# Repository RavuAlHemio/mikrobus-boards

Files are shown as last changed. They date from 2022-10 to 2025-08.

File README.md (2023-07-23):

# mikroBUS Boards

An assortment of boards that should be compatible with [MikroElektronika](https://www.mikroe.com/)'s [mikroBUS standard](https://download.mikroe.com/documents/standards/mikrobus/mikrobus-standard-specification-v200.pdf).

The designs are experimental. They are provided without warranty that the resulting boards will be fit for purpose and without warranty that they will not damage the connected devices.

## Boards

* `i2c-spi-jumper-mikrobus-board`: an I²C-to-SPI interface similar to the [_I2C to SPI Click_](https://www.mikroe.com/i2c-to-spi-click) (MIKROE-3743) and using the same chip ([NXP SC18IS602BIPW/S8HP](https://www.nxp.com/part/SC18IS602BIPW)), but with pin header jumpers instead of re-soldering 0Ω SMD "resistors" to set the I²C address. Perfect for people with no fine motor skills, like myself.

* `i2c-spi-jumper-mikrobus-board-var2`: another I²C-to-SPI interface with jumpers, but using the [NXP SC18IS606PW](https://www.nxp.com/part/SC18IS606PW), since the SC18IS602BIPW/S8HP is end-of-life. A different board is needed because the new chip has a different pinout.

* `i2c-spi-oled-mikrobus-board`: an I²C-to-SPI interface with a pinout that helps interoperability with the [_OLED C Click_] (https://www.mikroe.com/oled-c-click) (MIKROE-1585) by making some of its additional non-SPI pins accessible via I²C while isolating them from the microcontroller. To simplify the traces and keep the board a reasonable size, instead of providing a second pair of mikroBUS sockets to connect the SPI-enabled device, the design provides a [mikroBUS Shuttle](https://www.mikroe.com/mikrobus-shuttle) pin header.

* `i2c-uart-mikrobus-board`: just as the I²C-to-SPI boards allow SPI devices to be controlled via I²C, this board allows UART devices to be contacted via I²C. Based around the [NXP SC16IS740IPW](https://www.nxp.com/part/SC16IS740IPW). This board also provides a [mikroBUS Shuttle](https://www.mikroe.com/mikrobus-shuttle) pin header to connect the UART board. The I²C address is set using rotary switches.

* `knx-mikrobus-board`: a KNX bus coupling unit (BCU) that translates between KNX and UART. Based around the [onsemi NCN5130](https://www.onsemi.com/products/interfaces/wired-transceivers-modems/ncn5130) but should also work with the pin-compatible [onsemi NCN5121](https://www.onsemi.com/products/interfaces/wired-transceivers-modems/ncn5121).

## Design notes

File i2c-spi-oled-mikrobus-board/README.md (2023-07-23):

# `i2c-spi-oled-mikrobus-board`

I²C-to-SPI interface board with most mikroBUS pins controllable via I²C.

Combines two chips: SC18IS606PW (I²C-to-SPI) and PCA9557PW (I²C-to-GPIO).

## Addressing

Three bits of the address are chosen through the three jumpers on JP1. The bits are numbered, from
top to bottom, A0, A1, and A2. Bridging the left and middle pins with the jumper sets that bit to 0;
bridging the middle and right pins sets the bit to 1.

Once the jumpers are set, the following addresses are assigned to the chips:

| chip | MSB | b5 | b4 | b3 | b2 | b1 | LSB | (R/W) |
| --- | --- | -- | -- | -- | -- | -- | --- | ----- |
| SC18IS606PW | 0 | 1  | 0  | 1  | A2 | A1 | A0  | |
| PCA9557PW | 0 | 0  | 1  | 1  | A2 | A1 | A0  | |

### Communication

The shuttle board's peripheral select pin is connected to the SC18IS606PW's ¬SS0 pin. Therefore, to
send data via SPI, use function 0x01.

The non-SPI pins are connected to the PCA9557PW as follows:

| PCA9557PW | shuttle board |
| --- | --- |
| P0 | ¬INT |
| P1 | D/¬C |
| P2 | EN |
| P3 | R/¬W |
| P4 | ¬RST |

Pins P5 through P7 are unconnected.

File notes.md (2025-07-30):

## mikroBUS Shuttle

The pin header used by MikroElektronika for the mikroBUS Shuttle is a CNC 3221-16-0300-00, available from DigiKey (not Mouser). Most other shrouded pin headers do not have the "open sides" (or only have them at the bottom of the pin header but not near the top).

The canonical pin numbering for IDC connectors is:

1. The key is a protrusion on the connector with sockets (generally on a cable) and a hole on the connector with pins (generally on a device).

2. The row with the key or key-hole is the top row.

3. In the top row, position 1 is the leftmost socket (and, correspondingly, the rightmost pin) when staring at the mating surface of the connector.

4. Position 2 is in the next row right below position 1.

5. Once all rows are exhausted, counting continues at the next position in the top row.

Oddly enough, the Shuttle's ribbon cables are terminated in such a way that pin 1 is top-left on one end of the cable and top-right on the other. This means that the pinout of the Shuttle board (the remote base for a mikroBUS board) is different than that of the Shuttle Click board (the module that plugs into a host board).

Taking all of this into account, the socket pinouts on the boards are as follows, key-hole above the top row.

mikroBUS Shuttle (remote):

| | | | | | | | |
| ---:| -----:| ----:| ----:| ----:| ----:| ---:| ---:|
| GND | +3.3V | COPI | CIPO |  SCK | CS | RST |  AN |
|  15 | 13 | 11 | 9 | 7 | 5 | 3 | 1 |
|  16 | 14 | 12 | 10 | 8 | 6 | 4 | 2 |
| GND | +5V |  SDA |  SCL | CRPT | CTPR | INT | PWM |

(CRPT and CPTR are the UART pins: Controller Rx/Peripheral Tx and vice versa. The two GND pins are connected together on the Shuttle. The connector is mounted "key-up".)

Shuttle click (base):

| | | | | | | | |
| ---:| ---:| ----:| ----:| ----:| ----:| -----:| ---:|
| PWM | INT | CTPR | CRPT |  SCL |  SDA | +5V | GND |
|  15 |  13 | 11 | 9 | 7 | 5 | 3 | 1 |
|  16 |  14 | 12 | 10 | 8 | 6 | 4 | 2 |
|  AN | RST | CS |  SCK | CIPO | COPI | +3.3V | GND |

(Here, too, the ground pins are connected internally. The connector is mounted "key-down", but the above table is oriented "key-up".)

## ARM SWD debug port

The partially-shrouded 1.27mm pin header used for the ARM SWD debug port is a Samtec FTSH-105-01-F-DV-K-P. The -K specifies the keyed partial shroud and -P specifies a pick & place pad for simplified machine assembly.

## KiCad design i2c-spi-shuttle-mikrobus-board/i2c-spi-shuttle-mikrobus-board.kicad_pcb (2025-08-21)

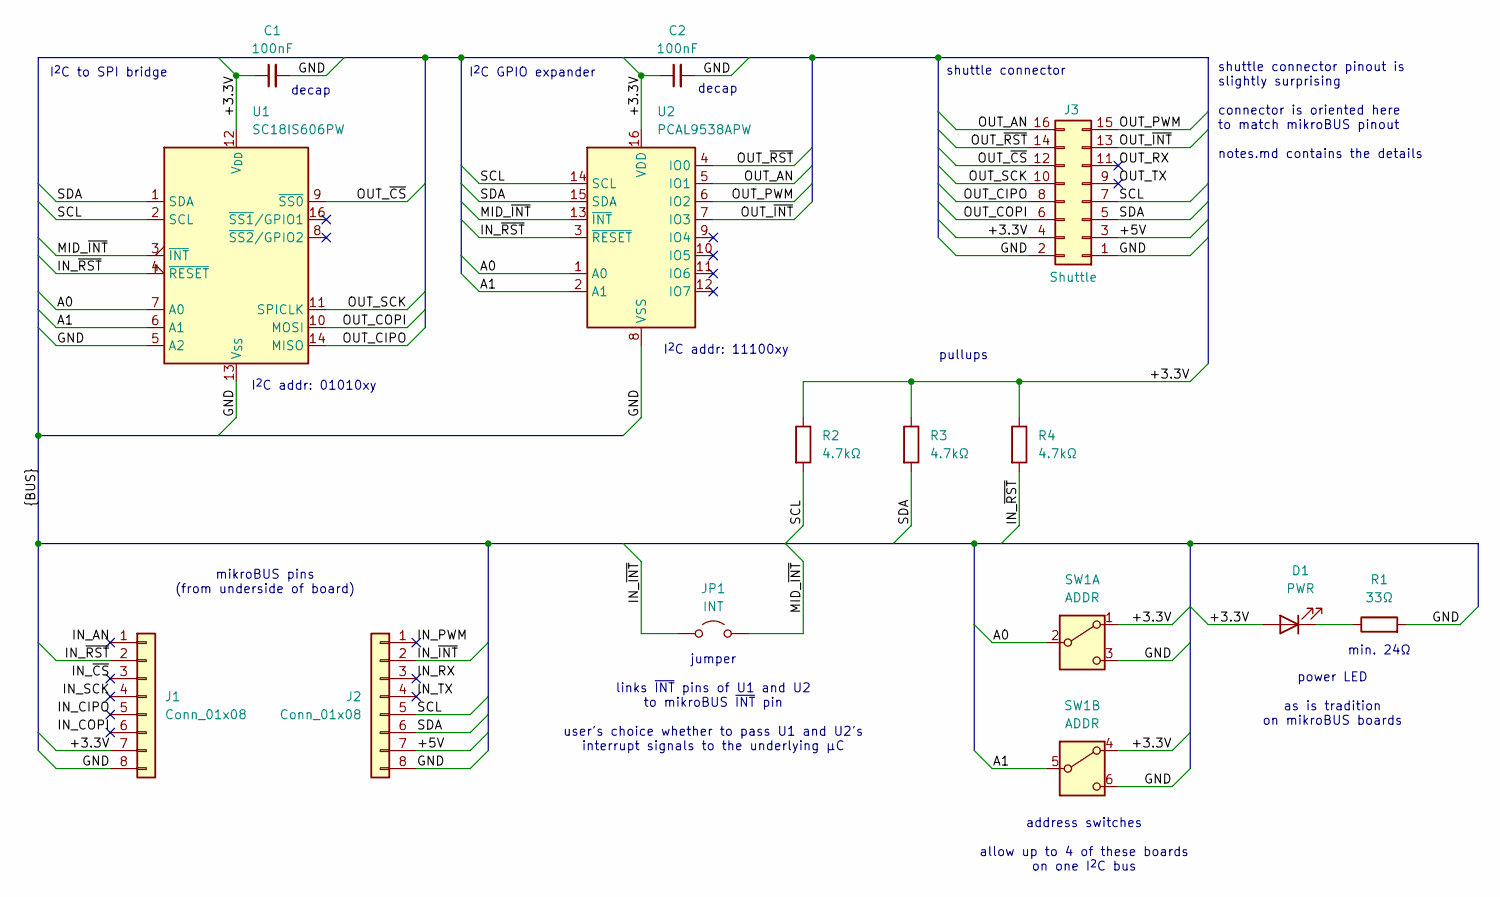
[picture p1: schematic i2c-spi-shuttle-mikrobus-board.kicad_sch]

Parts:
C1, C2: 100nF; C_0402_1005Metric; LCSC C307331
D1: PWR; LED_0805_2012Metric; LCSC C2297
J1, J2: Conn_01x08; PinHeader_1x08_P2.54mm_Vertical
J3: Shuttle; CNC_3221-16-0300-00; LCSC C5338669
JP1: INT; PinHeader_1x02_P2.54mm_Vertical
R1: 33Ω; R_0603_1608Metric; LCSC C23140
R2, R3, R4: 4.7kΩ; R_0402_1005Metric; LCSC C25900
SW1: ADDR; Nidec_Copal_CAS-D20A; LCSC C3664582
U1: SC18IS606PW; TSSOP-16_4.4x5mm_P0.65mm; LCSC C5190384
U2: PCAL9538APW; TSSOP-16_4.4x5mm_P0.65mm; LCSC C2652336

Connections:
/+3.3V: C1.1, C2.1, D1.2 (A), J1.7, J3.4, R2.1, R3.1, R4.1, SW1.1 (A), SW1.4 (A), U1.12 (V_{DD}), U1.15 (V_{DD}), U2.16 (VDD)
/+5V: J2.7, J3.3
/A0: SW1.2 (B), U1.7 (A0), U2.1 (A0)
/A1: SW1.5 (B), U1.6 (A1), U2.2 (A1)
/GND: C1.2, C2.2, J1.8, J2.8, J3.1, J3.2, R1.2, SW1.3 (C), SW1.6 (C), U1.5 (A2), U1.13 (V_{SS}), U2.8 (VSS)
/IN_AN: J1.1
/IN_CIPO: J1.5
/IN_COPI: J1.6
/IN_PWM: J2.1
/IN_RX: J2.3
/IN_SCK: J1.4
/IN_TX: J2.4
/IN_~CS: J1.3
/IN_~INT: J2.2, JP1.1 (A)
/IN_~RST: J1.2, R4.2, U1.4 (~RESET), U2.3 (~RESET)
/MID_~INT: JP1.2 (B), U1.3 (~INT), U2.13 (~INT)
/OUT_AN: J3.16, U2.5 (IO1)
/OUT_CIPO: J3.8, U1.14 (MISO)
/OUT_COPI: J3.6, U1.10 (MOSI)
/OUT_PWM: J3.15, U2.6 (IO2)
/OUT_RX: J3.11
/OUT_SCK: J3.10, U1.11 (SPICLK)
/OUT_TX: J3.9
/OUT_~CS: J3.12, U1.9 (~SS0)
/OUT_~INT: J3.13, U2.7 (IO3)
/OUT_~RST: J3.14, U2.4 (IO0)
/SCL: J2.5, J3.7, R2.2, U1.2 (SCL), U2.14 (SCL)
/SDA: J2.6, J3.5, R3.2, U1.1 (SDA), U2.15 (SDA)
unnamed: D1.1 (K), R1.1

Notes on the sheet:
address switches allow up to 4 of these boards on one I^{2}C bus
power LED as is tradition on mikroBUS boards
I^{2}C GPIO expander
min. 24Ω
I^{2}C to SPI bridge
shuttle connector pinout is slightly surprising connector is oriented here to match mikroBUS pinout notes.md contains the details
decap
jumper links ~{INT} pins of U1 and U2 to mikroBUS ~{INT} pin user's choice whether to pass U1 and U2's interrupt signals to the underlying µC
mikroBUS pins (from underside of board)
pullups
shuttle connector
I^{2}C addr: 11100xy
I^{2}C addr: 01010xy

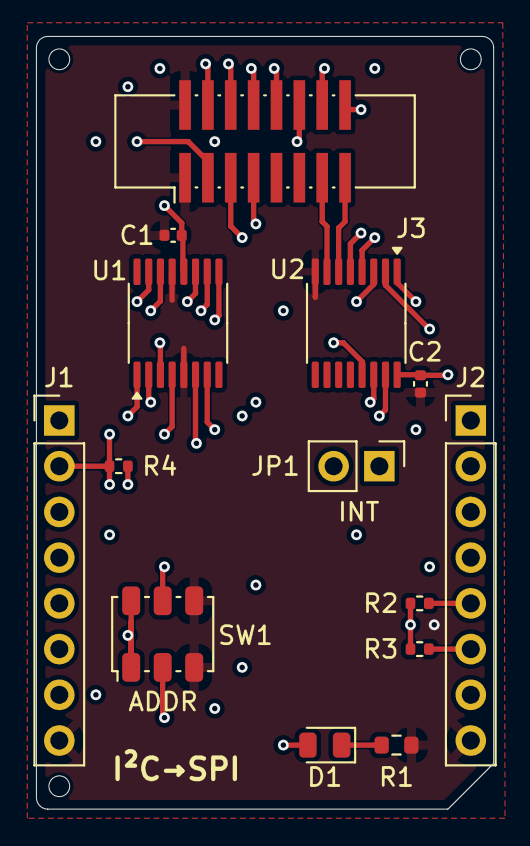
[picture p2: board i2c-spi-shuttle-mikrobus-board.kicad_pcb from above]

Board: 4 copper layers, 25.4 x 42.9 mm, 14 parts (0 on the bottom side), 19 nets.

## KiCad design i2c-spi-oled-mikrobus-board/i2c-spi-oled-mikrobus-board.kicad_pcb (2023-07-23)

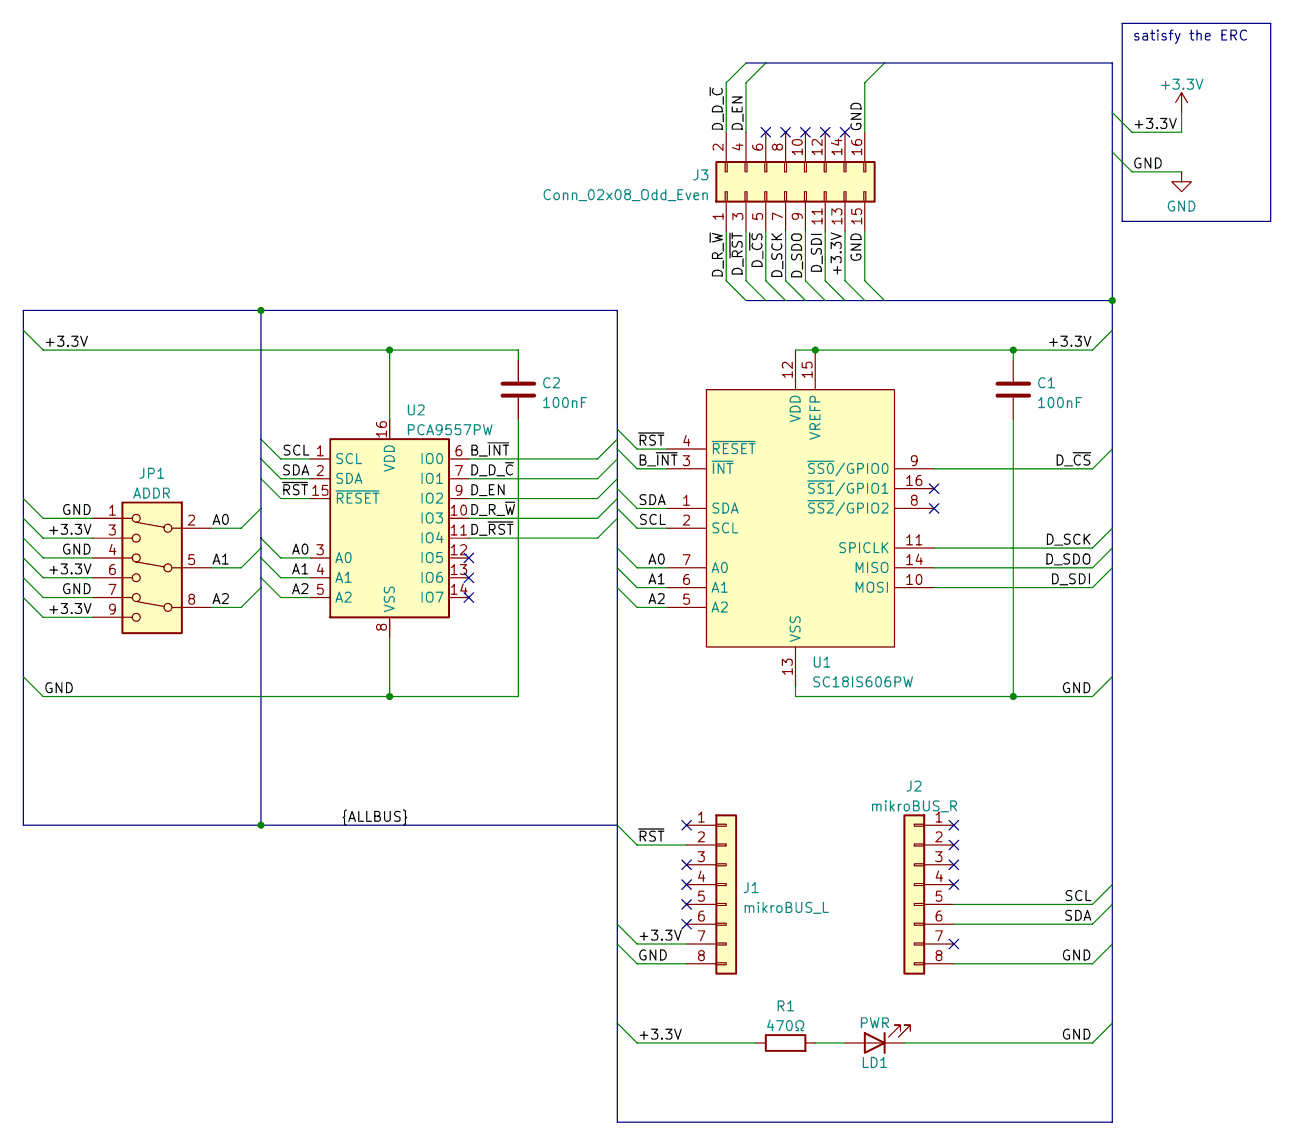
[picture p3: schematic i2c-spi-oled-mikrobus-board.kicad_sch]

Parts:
C1, C2: 100nF; C_0402_1005Metric; LCSC C307331
J1: mikroBUS_L; PinHeader_1x08_P2.54mm_Vertical
J2: mikroBUS_R; PinHeader_1x08_P2.54mm_Vertical
J3: Conn_02x08_Odd_Even; CNC_3221-16-0300-00; LCSC C5338669
JP1: ADDR; PinHeader_3x03_P2.54mm_Vertical
LD1: PWR; LED_0603_1608Metric; LCSC C72043
R1: 470Ω; R_0603_1608Metric; LCSC C23179
U1: SC18IS606PW; TSSOP-16_4.4x5mm_P0.65mm; LCSC C5190384
U2: PCA9557PW; TSSOP-16_4.4x5mm_P0.65mm; LCSC C141380

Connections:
+3.3V: C1.2, C2.2, J1.7, J3.13, JP1.3, JP1.6, JP1.9, R1.1, U1.12 (VDD), U1.15 (VREFP), U2.16 (VDD)
/A0: JP1.2, U1.7 (A0), U2.3 (A0)
/A1: JP1.5, U1.6 (A1), U2.4 (A1)
/A2: JP1.8, U1.5 (A2), U2.5 (A2)
/B_~INT: U1.3 (~INT), U2.6 (IO0)
/D_D_~C: J3.2, U2.7 (IO1)
/D_EN: J3.4, U2.9 (IO2)
/D_R_~W: J3.1, U2.10 (IO3)
/D_SCK: J3.7, U1.11 (SPICLK)
/D_SDI: J3.11, U1.10 (MOSI)
/D_SDO: J3.9, U1.14 (MISO)
/D_~CS: J3.5, U1.9 (~SS0/GPIO0)
/D_~RST: J3.3, U2.11 (IO4)
/SCL: J2.5, U1.2 (SCL), U2.1 (SCL)
/SDA: J2.6, U1.1 (SDA), U2.2 (SDA)
/~RST: J1.2, U1.4 (~RESET), U2.15 (~RESET)
GND: C1.1, C2.1, J1.8, J2.8, J3.15, J3.16, JP1.1, JP1.4, JP1.7, LD1.1 (K), U1.13 (VSS), U2.8 (VSS)
unnamed: LD1.2 (A), R1.2

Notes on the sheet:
satisfy the ERC

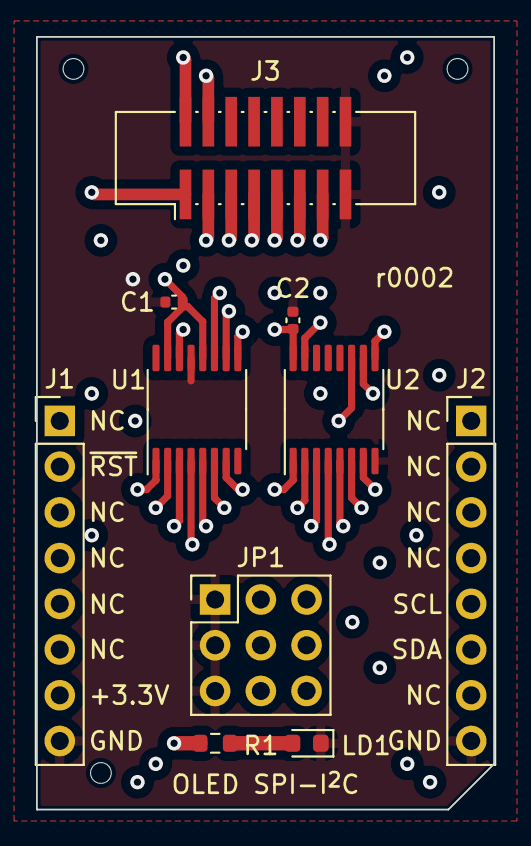
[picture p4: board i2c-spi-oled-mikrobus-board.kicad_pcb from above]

Board: 4 copper layers, 25.4 x 42.9 mm, 10 parts (0 on the bottom side), 18 nets.

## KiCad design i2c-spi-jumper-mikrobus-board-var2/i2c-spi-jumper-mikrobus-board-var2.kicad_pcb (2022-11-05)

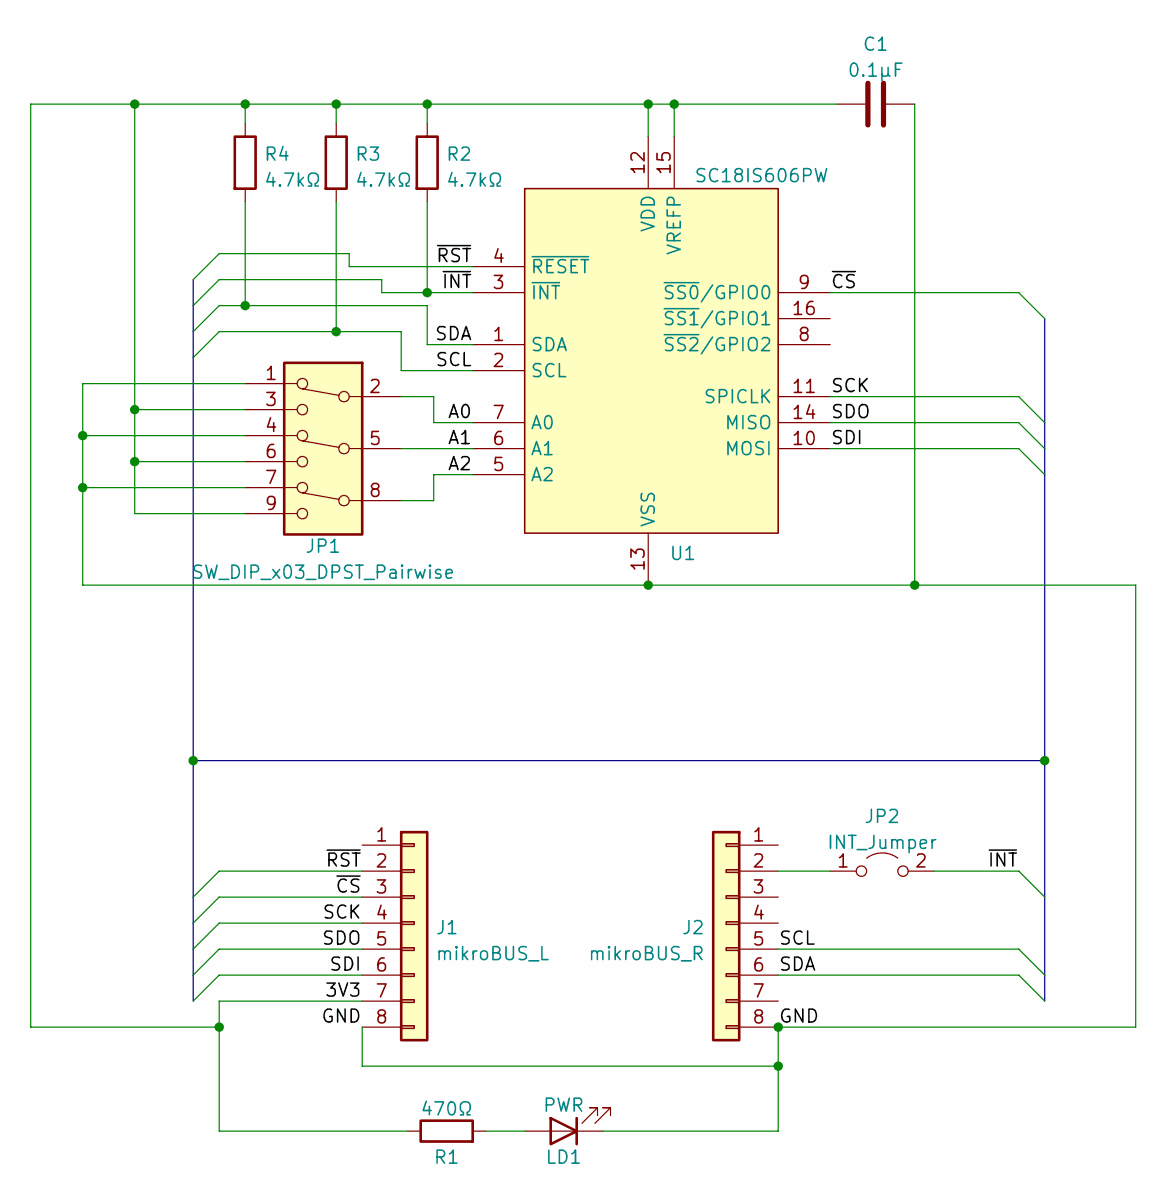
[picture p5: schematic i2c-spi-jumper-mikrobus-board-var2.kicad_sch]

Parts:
C1: 0.1µF; C_0402_1005Metric; LCSC C307331
J1: mikroBUS_L; PinHeader_1x08_P2.54mm_Vertical
J2: mikroBUS_R; PinHeader_1x08_P2.54mm_Vertical
JP1: SW_DIP_x03_DPST_Pairwise; PinHeader_3x03_P2.54mm_Vertical
JP2: INT_Jumper; PinHeader_1x02_P2.54mm_Vertical
LD1: PWR; LED_0603_1608Metric; LCSC C72043
R1: 470Ω; R_0603_1608Metric; LCSC C23179
R2, R3, R4: 4.7kΩ; R_0402_1005Metric; LCSC C25900
U1: SC18IS606PW; TSSOP-16_4.4x5mm_P0.65mm; LCSC C5190384

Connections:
/3V3: C1.1, J1.7, JP1.3, JP1.6, JP1.9, R1.1, R2.1, R3.1, R4.1, U1.12 (VDD), U1.15 (VREFP)
/A0: JP1.2, U1.7 (A0)
/A1: JP1.5, U1.6 (A1)
/A2: JP1.8, U1.5 (A2)
/GND: C1.2, J1.8, J2.8, JP1.1, JP1.4, JP1.7, LD1.1 (K), U1.13 (VSS)
/SCK: J1.4, U1.11 (SPICLK)
/SCL: J2.5, R3.2, U1.2 (SCL)
/SDA: J2.6, R4.2, U1.1 (SDA)
/SDI: J1.6, U1.10 (MOSI)
/SDO: J1.5, U1.14 (MISO)
/~CS: J1.3, U1.9 (~SS0/GPIO0)
/~INT: JP2.2 (B), R2.2, U1.3 (~INT)
/~RST: J1.2, U1.4 (~RESET)
unnamed: J2.2, JP2.1 (A)
unnamed: LD1.2 (A), R1.2

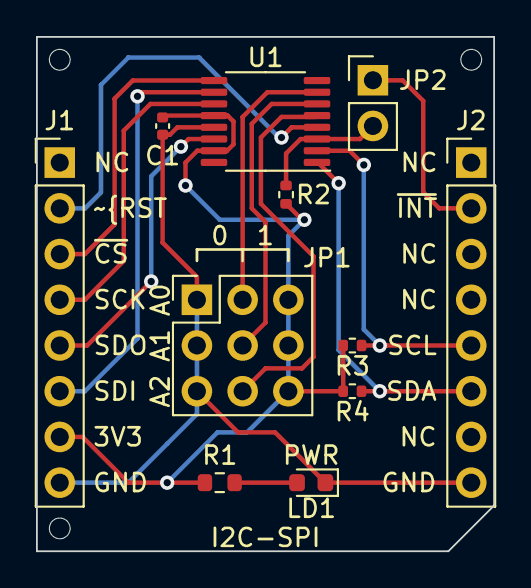
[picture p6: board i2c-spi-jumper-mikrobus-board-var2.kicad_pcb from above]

Board: 2 copper layers, 25.4 x 28.6 mm, 11 parts (0 on the bottom side), 15 nets.

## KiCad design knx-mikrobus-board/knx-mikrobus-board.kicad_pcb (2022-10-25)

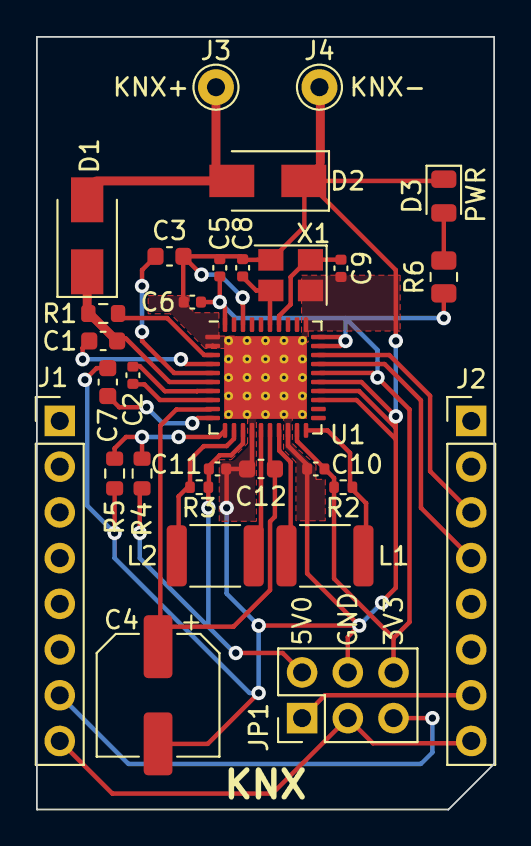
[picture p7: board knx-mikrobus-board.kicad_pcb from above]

Board: 2 copper layers, 25.4 x 42.9 mm, 30 parts (0 on the bottom side), 25 nets.

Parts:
C1: 47nF; C_0603_1608Metric
C2: 220nF; C_0402_1005Metric
C3, C12: 100nF; C_0603_1608Metric
C4: 100μF; CP_Elec_6.3x5.7
C5, C6: 100nF; C_0402_1005Metric
C7: 1µF; C_0603_1608Metric
C8, C9: 9pF; C_0402_1005Metric
C10, C11: 10µF; C_0402_1005Metric
D1: SS16; D_SMA
D2: SMAJ40CA; D_SMA
D3: LED; LED_0805_2012Metric
J1: mikroBUS_L; PinHeader_1x08_P2.54mm_Vertical
J2: mikroBUS_R; PinHeader_1x08_P2.54mm_Vertical
J3: KNX+; Pin_D1.0mm_L10.0mm
J4: KNX-; Pin_D1.0mm_L10.0mm
JP1: SW_DIP_x03; PinHeader_2x03_P2.54mm_Vertical
L1, L2: 220µH; L_1812_4532Metric
R1: 27Ω; R_0603_1608Metric
R2, R3: 1Ω; R_0402_1005Metric
R4: 180kΩ; R_0603_1608Metric
R5: 56kΩ; R_0603_1608Metric
R6: 470Ω; R_0805_2012Metric
U1: NCN5130; QFN-40-1EP_6x6mm_P0.5mm_EP4.6x4.6mm_ThermalVias
X1: 16MHz; Crystal_SMD_3225-4Pin_3.2x2.5mm

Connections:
/+3.3V: J1.7, JP1.5
/+5V: J2.7, JP1.1
/GND: J1.8, J2.8, JP1.3
/RX: J2.4, U1.27 (SDI/RXD)
/TX: J2.3, U1.28 (SDO/TXD)
/knx-logic/+3.3V: C5.2, C6.2, C10.1, JP1.6, R2.1, R6.1, U1.19 (VDD1), U1.26 (CSB/UC1), U1.29 (SCK/UC2), U1.30 (VDDD), U1.40 (VDDA)
/knx-logic/+5V: C11.1, JP1.2, R3.1, R4.1, U1.13 (VDD2)
/knx-logic/GND: C3.2, C4.2, C5.1, C6.1, C7.2, C8.2, C9.2, C10.2, C11.2, C12.1, D2.1 (A1), D3.1 (K), J4.1, JP1.4, R5.2, U1.1 (VSSA), U1.2 (VBUS2), U1.14 (VSS2), U1.18 (VSS1), U1.23 (MODE1), U1.24 (MODE2), U1.25 (TREQ), U1.31 (VSSD), U1.38 (FANIN), U1.41 (GND_PLANE), X1.2, X1.4
/knx-logic/KNX_+: D1.2 (A), D2.2 (A2), J3.1
unnamed: C1.1, U1.4 (CCP)
unnamed: C1.2, D1.1 (K), R1.2, U1.6 (VBUS1)
unnamed: C2.1, U1.8 (CEQ2)
unnamed: C2.2, U1.7 (CEQ1)
unnamed: C3.1, U1.5 (CAV)
unnamed: C7.1, U1.10 (V20V)
unnamed: C8.1, U1.35 (XTAL1), X1.3
unnamed: C9.1, U1.34 (XTAL2), X1.1
unnamed: C4.1, C12.2, U1.9 (VFILT), U1.16 (VIN)
unnamed: D3.2 (A), R6.2
unnamed: L1.1, R2.2, U1.20 (VDD1M)
unnamed: L1.2, U1.17 (VSW1)
unnamed: L2.1, R3.2, U1.12 (VDD2MC)
unnamed: L2.2, U1.15 (VSW2)
unnamed: R1.1, U1.3 (TXO)
unnamed: R4.2, R5.1, U1.11 (VDD2MV)

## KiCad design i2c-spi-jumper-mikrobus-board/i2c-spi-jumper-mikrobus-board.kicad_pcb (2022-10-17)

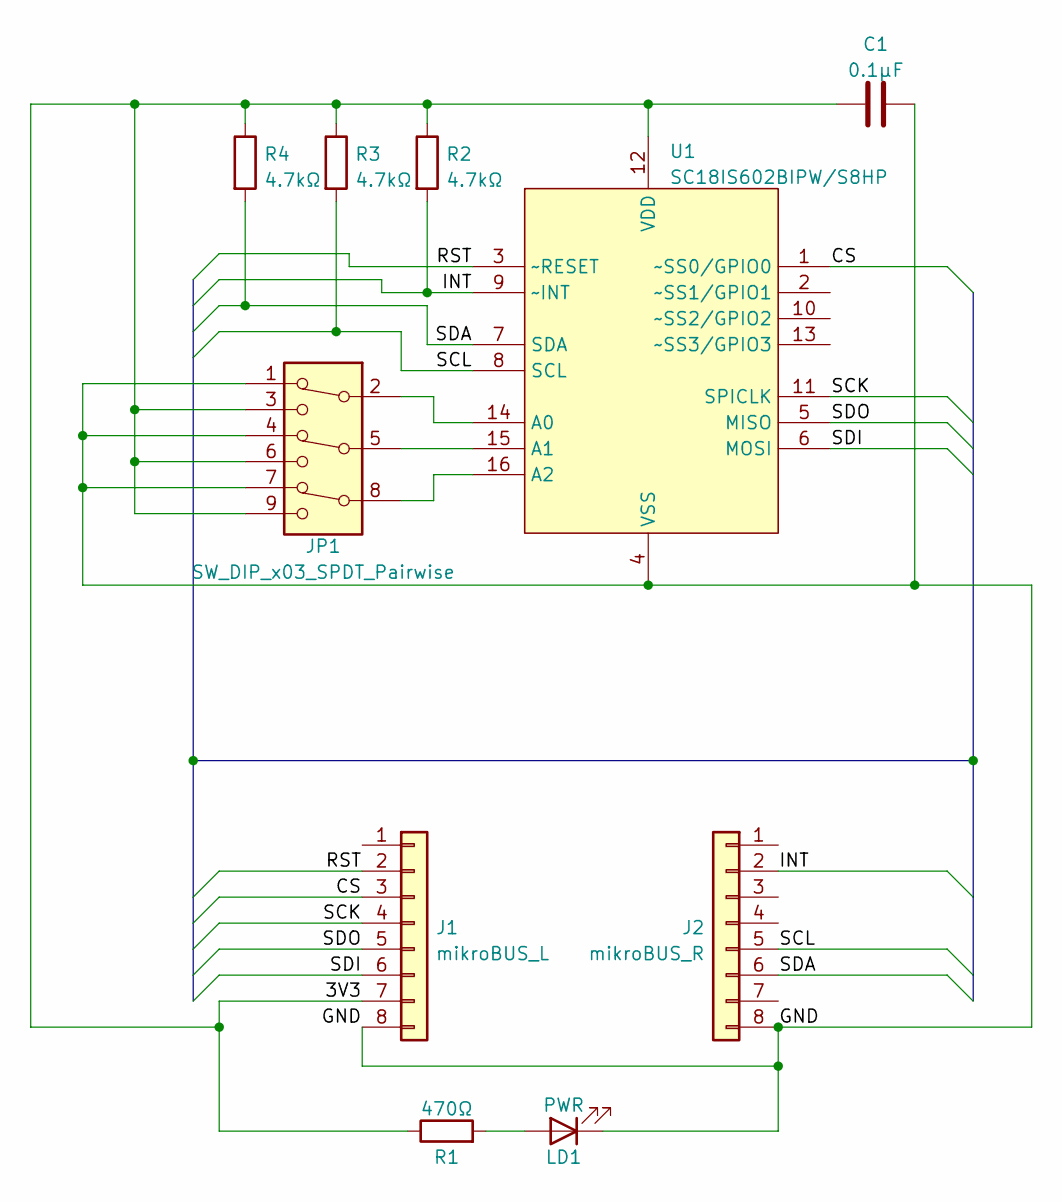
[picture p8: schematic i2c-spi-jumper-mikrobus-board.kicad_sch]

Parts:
C1: 0.1µF; C_0402_1005Metric; LCSC C307331
J1: mikroBUS_L; PinHeader_1x08_P2.54mm_Vertical
J2: mikroBUS_R; PinHeader_1x08_P2.54mm_Vertical
JP1: SW_DIP_x03_SPDT_Pairwise; PinHeader_3x03_P2.54mm_Vertical
LD1: PWR; LED_0805_2012Metric; LCSC C73548
R1: 470Ω; R_0805_2012Metric; LCSC C17673
R2, R3, R4: 4.7kΩ; R_0402_1005Metric; LCSC C25900
U1: SC18IS602BIPW/S8HP; TSSOP-16_4.4x5mm_P0.65mm; LCSC C2678036

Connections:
/3V3: C1.1, J1.7, JP1.3, JP1.6, JP1.9, R1.1, R2.1, R3.1, R4.1, U1.12 (VDD)
/CS: J1.3, U1.1 (~SS0/GPIO0)
/GND: C1.2, J1.8, J2.8, JP1.1, JP1.4, JP1.7, LD1.1 (K), U1.4 (VSS)
/INT: J2.2, R2.2, U1.9 (~INT)
/RST: J1.2, U1.3 (~RESET)
/SCK: J1.4, U1.11 (SPICLK)
/SCL: J2.5, R3.2, U1.8 (SCL)
/SDA: J2.6, R4.2, U1.7 (SDA)
/SDI: J1.6, U1.6 (MOSI)
/SDO: J1.5, U1.5 (MISO)
unnamed: JP1.2, U1.14 (A0)
unnamed: JP1.5, U1.15 (A1)
unnamed: JP1.8, U1.16 (A2)
unnamed: LD1.2 (A), R1.2

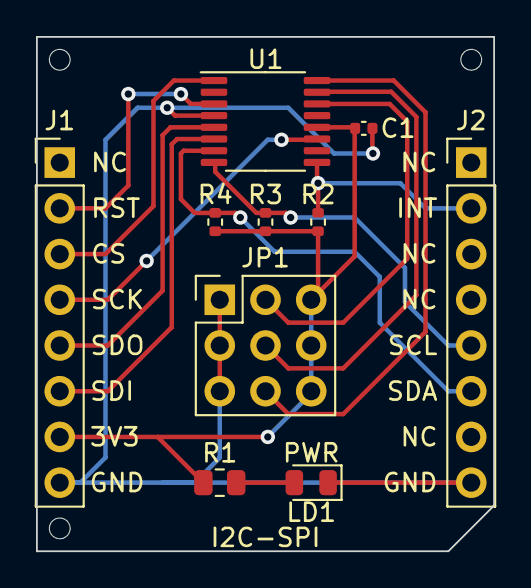
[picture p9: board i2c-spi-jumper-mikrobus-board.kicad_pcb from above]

Board: 2 copper layers, 25.4 x 28.6 mm, 10 parts (0 on the bottom side), 14 nets.

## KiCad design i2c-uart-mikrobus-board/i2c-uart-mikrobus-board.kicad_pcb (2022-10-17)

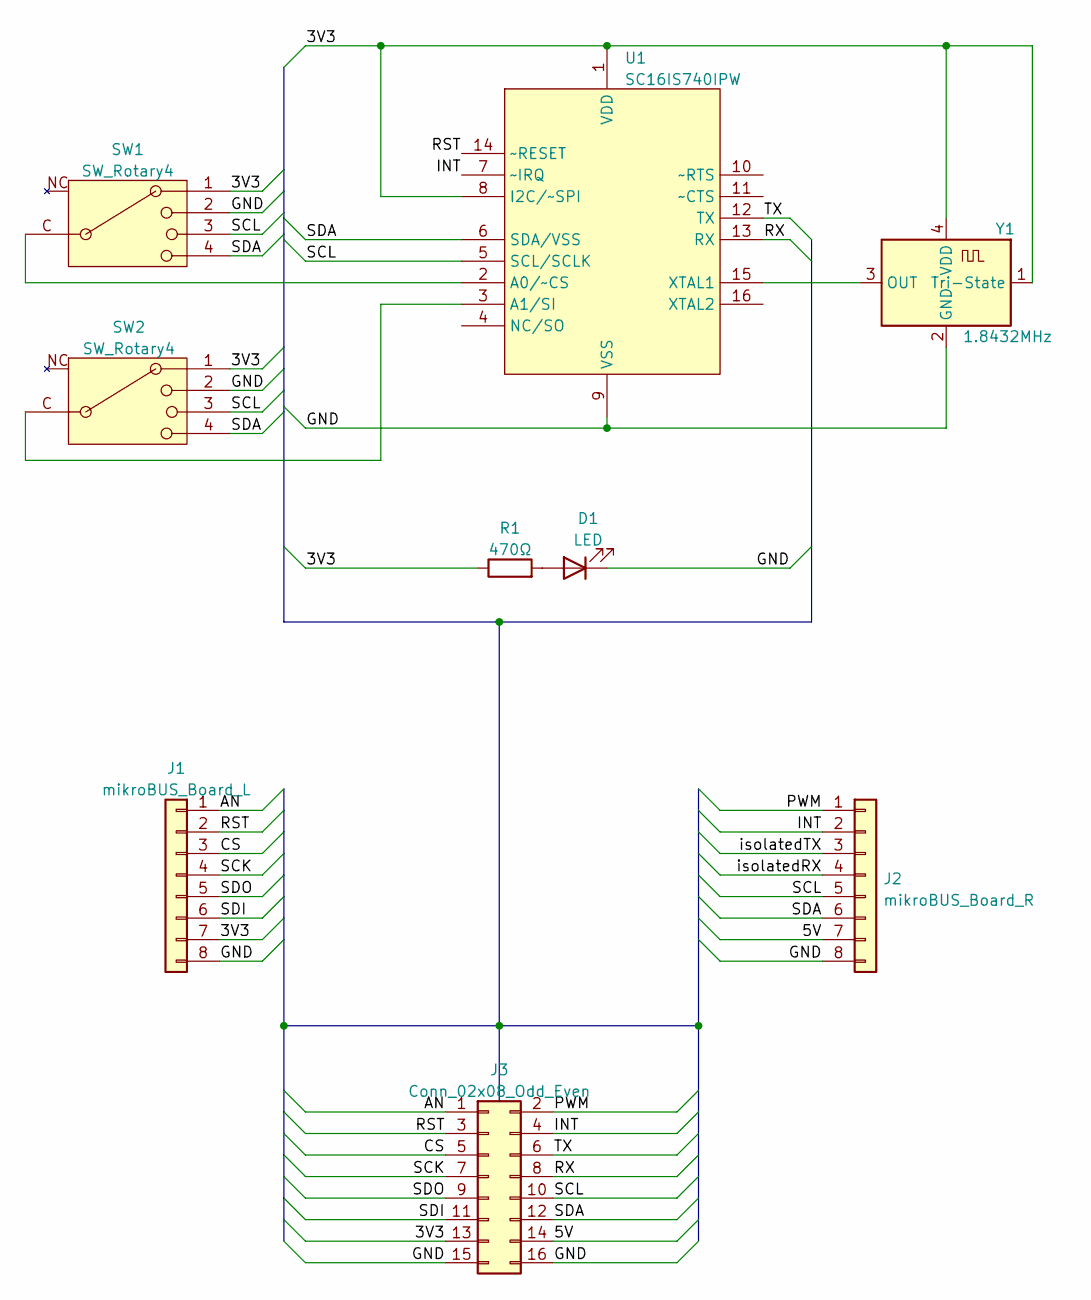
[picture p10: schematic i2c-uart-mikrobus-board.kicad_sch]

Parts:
D1: LED; LED_0805_2012Metric
J1: mikroBUS_Board_L; PinHeader_1x08_P2.54mm_Vertical
J2: mikroBUS_Board_R; PinHeader_1x08_P2.54mm_Vertical
J3: Conn_02x08_Odd_Even; CNC_3221-16-0300-00
R1: 470Ω; R_0805_2012Metric
SW1, SW2: SW_Rotary4; Nidec_Copal_CS-4-14NB; Mouser 229-CS-4-14NTB
U1: SC16IS740IPW; TSSOP-16_4.4x5mm_P0.65mm; Mouser 771-SC16IS0IPW128
Y1: 1.8432MHz; Oscillator_SMD_ECS_2520MV-xxx-xx-4Pin_2.5x2.0mm; Mouser 520-3225MVLC-018CNTR

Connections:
/3V3: J1.7, J3.13, R1.1, SW1.1, SW2.1, U1.1 (VDD), U1.8 (I2C/~SPI), Y1.1 (Tri-State), Y1.4 (VDD)
/5V: J2.7, J3.14
/AN: J1.1, J3.1
/CS: J1.3, J3.5
/GND: D1.1 (K), J1.8, J2.8, J3.15, J3.16, SW1.2, SW2.2, U1.9 (VSS), Y1.2 (GND)
/INT: J2.2, J3.4, U1.7 (~IRQ)
/PWM: J2.1, J3.2
/RST: J1.2, J3.3, U1.14 (~RESET)
/RX: J3.8, U1.13 (RX)
/SCK: J1.4, J3.7
/SCL: J2.5, J3.10, SW1.3, SW2.3, U1.5 (SCL/SCLK)
/SDA: J2.6, J3.12, SW1.4, SW2.4, U1.6 (SDA/VSS)
/SDI: J1.6, J3.11
/SDO: J1.5, J3.9
/TX: J3.6, U1.12 (TX)
/isolatedRX: J2.4
/isolatedTX: J2.3
unnamed: D1.2 (A), R1.2
unnamed: SW1.C, U1.2 (A0/~CS)
unnamed: SW2.C, U1.3 (A1/SI)
unnamed: U1.15 (XTAL1), Y1.3 (OUT)

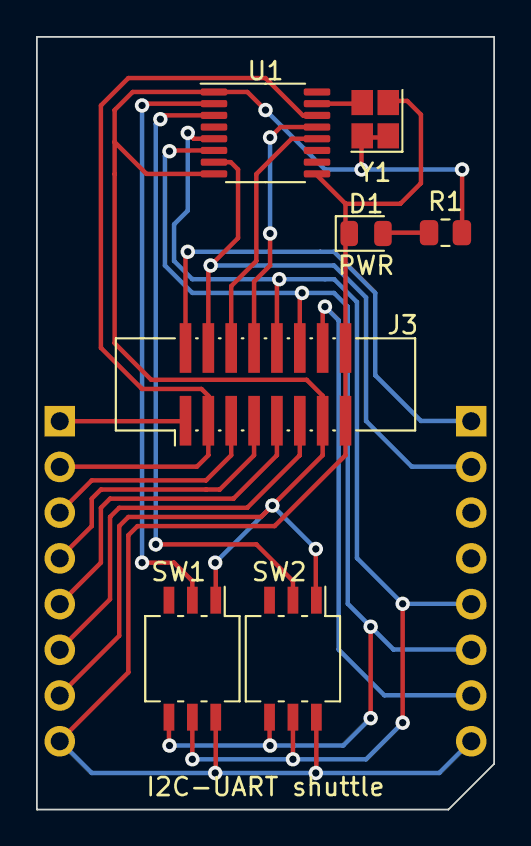
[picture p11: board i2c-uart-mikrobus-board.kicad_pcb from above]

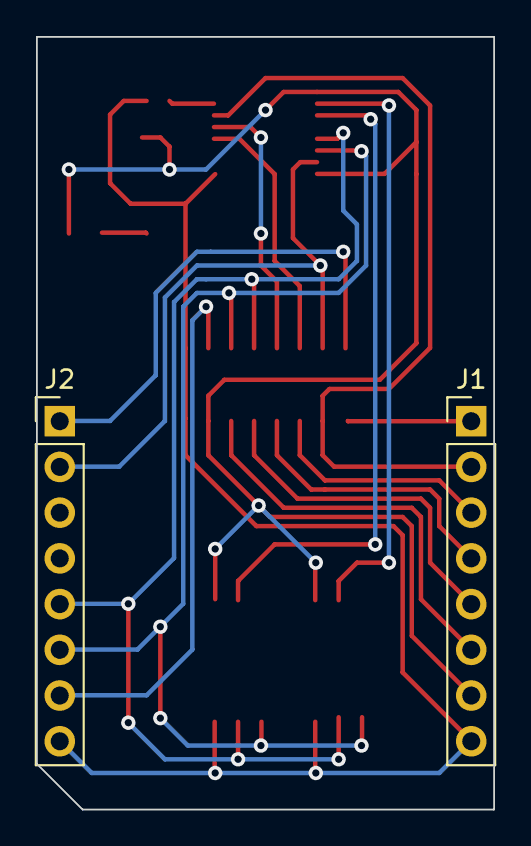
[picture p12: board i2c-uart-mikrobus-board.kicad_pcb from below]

Board: 2 copper layers, 25.4 x 42.9 mm, 9 parts (2 on the bottom side), 19 nets.

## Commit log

2022-10-17 i2c-uart: fix rotary switch orientation
    [i2c-uart-mikrobus-board.kicad_pcb]
2022-10-17 i2c-spi-jumper-var2: exclude THT headers from BOM
    [i2c-spi-jumper-mikrobus-board-var2.kicad_pcb]
2022-10-17 i2c-spi-jumper-var2: fix LCSC number of chip
    we had the old one listed
    [i2c-spi-jumper-mikrobus-board-var2.kicad_sch]
2022-10-17 i2c-uart: center Shuttle pin header footprint
    [i2c-uart-mikrobus-board.kicad_pcb]
2022-10-17 i2c-spi-jumper: mounting holes are of type "Other"
    [i2c-spi-jumper-mikrobus-board.kicad_pcb]
2022-10-25 knx: add ground plane
    [knx-logic.kicad_sch, knx-mikrobus-board.kicad_pcb]
2022-10-26 i2c-spi-jumper-var2: add JLCPCB mounting holes
    [i2c-spi-jumper-mikrobus-board-var2.kicad_pcb]
2022-11-05 i2c-spi-jumper-var2: fix signal negation
    [i2c-spi-jumper-mikrobus-board-var2.kicad_sch]
2022-11-05 i2c-spi-jumper-var2: add jumper to enable/disable ~INT pin connection
    This allows mikroBUS boards like the OLED C click to be used with this
    board without causing their Enable pin, which shares its location with the
    ~Interrupt pin, to be pulled low after SPI communication completes.
    [i2c-spi-jumper-mikrobus-board-var2.kicad_pcb, i2c-spi-jumper-mikrobus-board-var2.kicad_sch, i2c-uart-mikrobus-board.kicad_sch]
2022-12-16 add I2C SPI OLED mikroBUS board
    [i2c-spi-oled-mikrobus-board.kicad_pcb, i2c-spi-oled-mikrobus-board.kicad_sch]
2022-12-16 make I2C interface symbol fit default grid
2022-12-16 i2c-spi-oled: also connect the R/~W pin
    the display doesn't need it (it will be held to GND) but we might reuse
    this board for other SPI components
    [i2c-spi-oled-mikrobus-board.kicad_pcb, i2c-spi-oled-mikrobus-board.kicad_sch]
2023-04-30 oled: add JLCPCB mounting holes
    [i2c-spi-oled-mikrobus-board.kicad_pcb]
2023-04-30 oled: add README with pertinent I2C info
2023-07-23 README: fix description of i2c-spi-oled-mikrobus-board
2023-07-23 i2c-spi-oled: put ~RST signal on port expander too
    [i2c-spi-oled-mikrobus-board.kicad_pcb, i2c-spi-oled-mikrobus-board.kicad_sch]
2023-07-23 i2c-spi-oled: document P4
2025-07-05 notes: add note about ARM debug connector
2025-07-27 start i2c-spi-shuttle-mikrobus-board
    no progress yet because I'll be contributing symbols to KiCad first
    [i2c-spi-shuttle-mikrobus-board.kicad_pcb, i2c-spi-shuttle-mikrobus-board.kicad_sch]
2025-07-28 first version of i2c-spi-shuttle-mikrobus-board
    TODO:
    * purpose of board on silkscreen
    * some pin explanations on silkscreen (probably rear)
    * check if shuttle connector is oriented correctly!
    (MikroE schematics are inconsistent, test with multimeter)
    [i2c-spi-shuttle-mikrobus-board.kicad_pcb, i2c-spi-shuttle-mikrobus-board.kicad_sch]
2025-07-28 document more about the Shuttle boards
2025-07-28 fix shuttle pinout in schematic, clear PCB of tracks (we must reroute)
    [i2c-spi-shuttle-mikrobus-board.kicad_pcb, i2c-spi-shuttle-mikrobus-board.kicad_sch]
2025-07-29 route the I2C-SPI Shuttle board now that the pinout is fixed
    [i2c-spi-shuttle-mikrobus-board.kicad_pcb, i2c-spi-shuttle-mikrobus-board.kicad_sch]
2025-07-29 annotate schematic & board, pass +5V, update constraints
    [i2c-spi-shuttle-mikrobus-board.kicad_pcb, i2c-spi-shuttle-mikrobus-board.kicad_sch]
2025-07-29 add LCSC numbers
    [i2c-spi-shuttle-mikrobus-board.kicad_pcb, i2c-spi-shuttle-mikrobus-board.kicad_sch]
2025-07-30 notes: clarify Shuttle base connector orientation
2025-08-21 i2c spi shuttle: add mounting holes, JLC number placeholder, front label
    [i2c-spi-shuttle-mikrobus-board.kicad_pcb]
